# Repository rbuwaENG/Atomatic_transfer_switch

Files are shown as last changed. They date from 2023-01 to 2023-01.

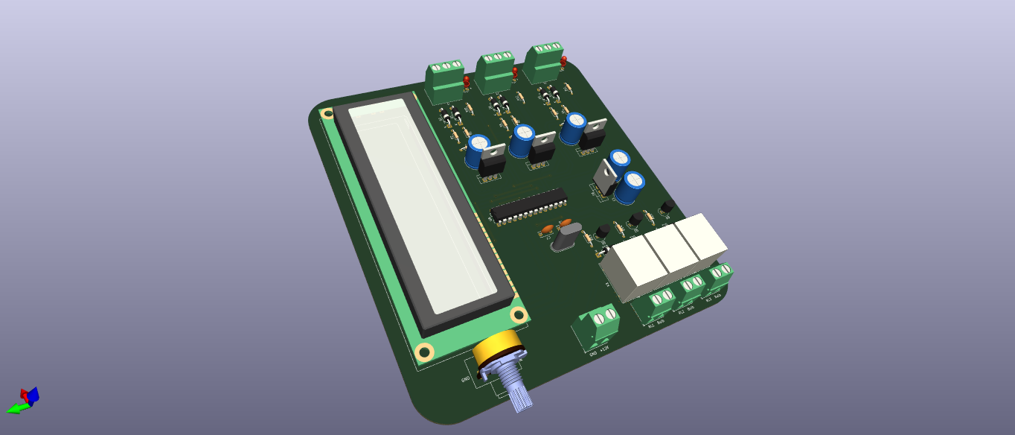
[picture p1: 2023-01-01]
pcb_design_kicad/src/img_2.png

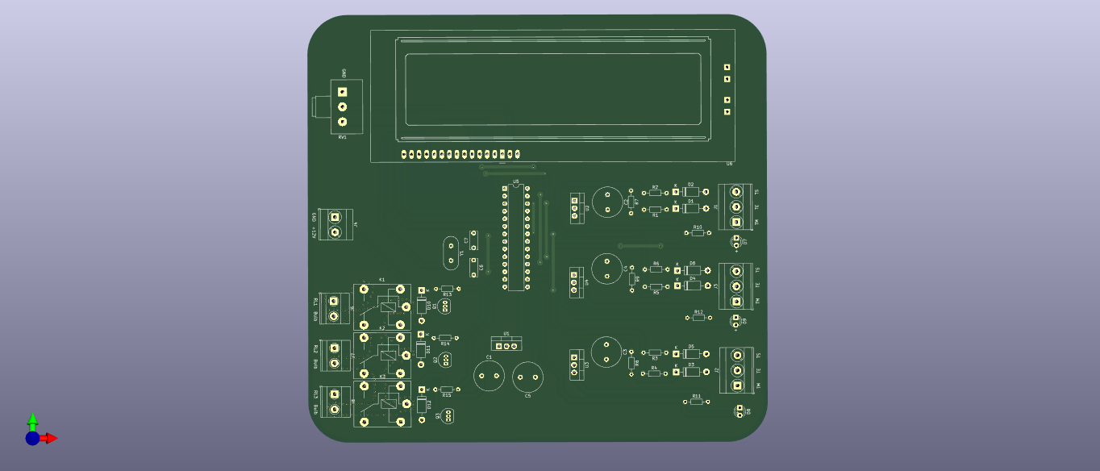
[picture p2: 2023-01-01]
pcb_design_kicad/src/img_3.png

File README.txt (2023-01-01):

░█████╗░████████╗░██████╗
██╔══██╗╚══██╔══╝██╔════╝
███████║░░░██║░░░╚█████╗░
██╔══██║░░░██║░░░░╚═══██╗
██║░░██║░░░██║░░░██████╔╝
╚═╝░░╚═╝░░░╚═╝░░░╚═════╝░
DESIGNED BY R.I BUWANEKA 
PCB,CIRCUIT DESIGNING SOLUTION 
WHATSAPP:0782532299

STEPS:
1.ARDUINO IDE-->IN PREFERENCE TICK UPLOAD 
2.THEN GET HEX FILE
1.UPLOAD HEX FILE FROM ARDUINO CODE
2.HIT PLAY BUTTON

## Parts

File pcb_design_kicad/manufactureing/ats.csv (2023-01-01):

Source: | /home/tharindu/Documents/Project/at_switch/ats/ats.kicad_sch
Date: | Sat 10 Sep 2022 11:17:41 AM +0530
Tool: | Eeschema 6.0.6-3a73a75311~116~ubuntu22.04.1
Generator: | /usr/share/kicad/plugins/bom_csv_grouped_by_value_with_fp.py
Component Count: | 53
Ref | Qnty | Value | Cmp name | Footprint | Description | Vendor
C1, C2, C3, C4, C5, | 5 | 2200u | C | Capacitor_THT:C_Radial_D10.0mm_H12.5mm_P5.00mm | Unpolarized capacitor
C6, C7, | 2 | 22p | C | Capacitor_THT:C_Disc_D6.0mm_W2.5mm_P5.00mm | Unpolarized capacitor
D1, D2, D3, D4, D5, D6, D10, D11, D12, | 9 | 1N4007 | 1N4007 | Diode_THT:D_DO-41_SOD81_P10.16mm_Horizontal | 1000V 1A General Purpose Rectifier Diode, DO-41
D7, D8, D9, | 3 | LED | LED | LED_THT:LED_D3.0mm | Light emitting diode
J1, J2, J3, | 3 | Screw_Terminal_01x03 | Screw_Terminal_01x03 | TerminalBlock_Phoenix:TerminalBlock_Phoenix_MKDS-3-3-5.08_1x03_P5.08mm_Horizontal | Generic screw terminal, single row, 01x03, script generated (kicad-library-utils/schlib/autogen/connector/)
J4, | 1 | Screw_Terminal_01x02 | Screw_Terminal_01x02 | TerminalBlock_Phoenix:TerminalBlock_Phoenix_MKDS-3-2-5.08_1x02_P5.08mm_Horizontal | Generic screw terminal, single row, 01x02, script generated (kicad-library-utils/schlib/autogen/connector/)
J5, | 1 | Screw_Terminal_01x04 | Screw_Terminal_01x04 | TerminalBlock_Phoenix:TerminalBlock_Phoenix_MKDS-3-4-5.08_1x04_P5.08mm_Horizontal | Generic screw terminal, single row, 01x04, script generated (kicad-library-utils/schlib/autogen/connector/)
K1, K2, K3, | 3 | FINDER-32.21-x300 | FINDER-32.21-x300 | Relay_THT:Relay_SPDT_Finder_36.11 | FINDER 32.21-x300, Single Pole Relay SPST-NO, 6A
Q1, Q2, Q3, | 3 | BC547 | BC547 | Package_TO_SOT_THT:TO-92_Inline | 0.1A Ic, 45V Vce, Small Signal NPN Transistor, TO-92
R1, R3, R5, | 3 | 100k | R | Resistor_THT:R_Axial_DIN0204_L3.6mm_D1.6mm_P7.62mm_Horizontal | Resistor
R2, R4, R6, R13, R14, R15, | 6 | 10k | R | Resistor_THT:R_Axial_DIN0204_L3.6mm_D1.6mm_P7.62mm_Horizontal | Resistor
R7, R8, R9, | 3 | 1k | R | Resistor_THT:R_Axial_DIN0204_L3.6mm_D1.6mm_P7.62mm_Horizontal | Resistor
R10, R11, | 2 | 330 | R | Resistor_THT:R_Axial_DIN0204_L3.6mm_D1.6mm_P7.62mm_Horizontal | Resistor
R12, | 1 | 300 | R | Resistor_THT:R_Axial_DIN0204_L3.6mm_D1.6mm_P7.62mm_Horizontal | Resistor
RV1, | 1 | 10k | R_Potentiometer | Potentiometer_THT:Potentiometer_Alps_RK163_Single_Horizontal | Potentiometer
U1, U2, U3, U4, | 4 | LM7805_TO220 | LM7805_TO220 | Package_TO_SOT_THT:TO-220-3_Vertical | Positive 1A 35V Linear Regulator, Fixed Output 5V, TO-220
U5, | 1 | ATmega328P-P | ATmega328P-P | Package_DIP:DIP-28_W7.62mm | 20MHz, 32kB Flash, 2kB SRAM, 1kB EEPROM, DIP-28
U6, | 1 | LCD-016N002L | LCD-016N002L | Display:LCD-016N002L | LCD 12x2, 8 bit parallel bus, 3V or 5V VDD
Y1, | 1 | Crystal | Crystal | Crystal:Crystal_HC18-U_Vertical | Two pin crystal

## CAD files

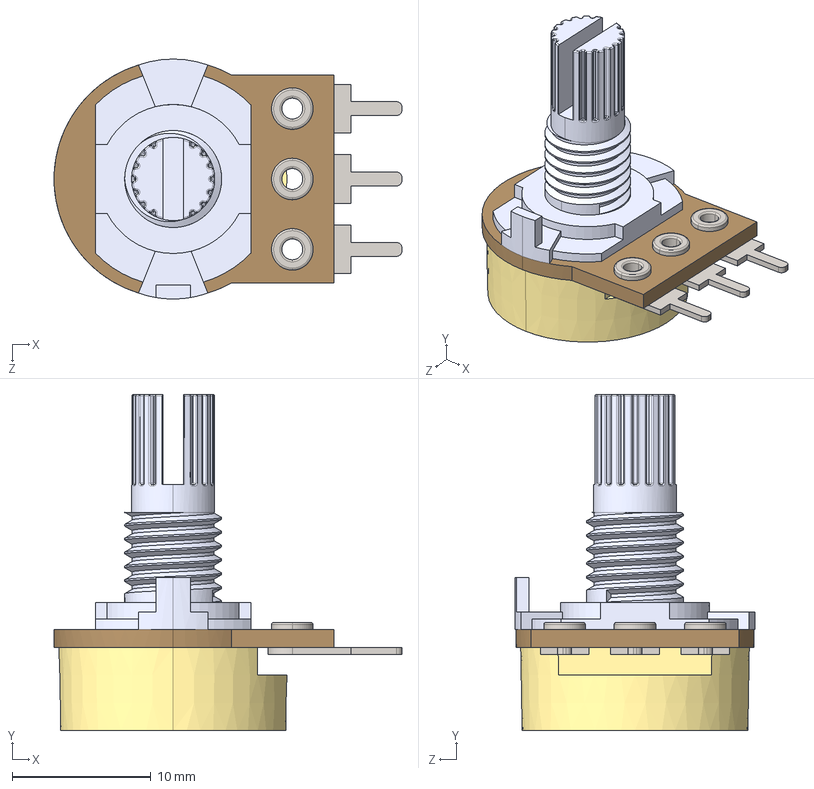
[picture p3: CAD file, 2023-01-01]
pcb_design_kicad/3d_model/potenciometer.STEP
25.1 x 24.2 x 17.3 mm

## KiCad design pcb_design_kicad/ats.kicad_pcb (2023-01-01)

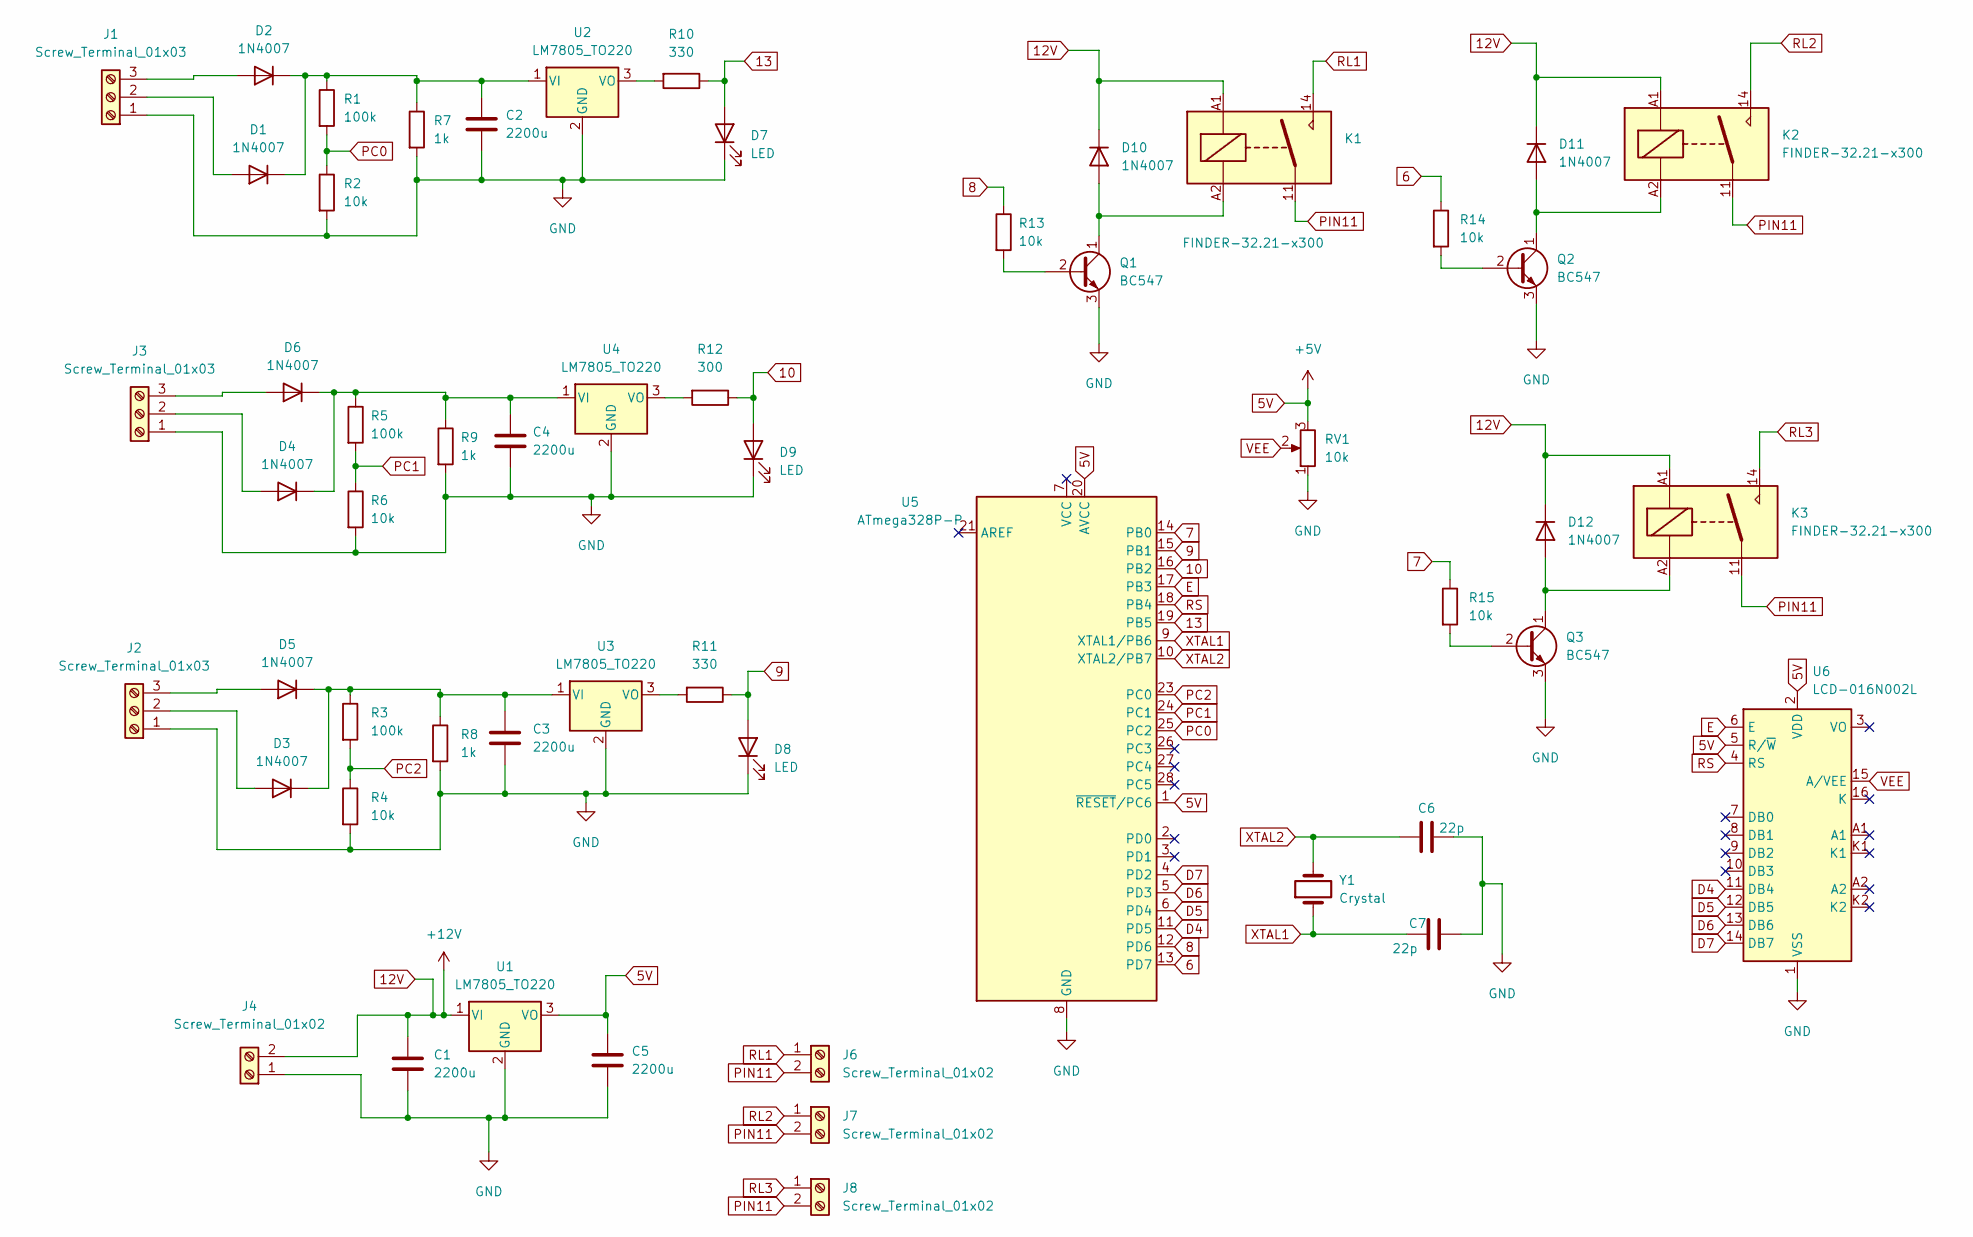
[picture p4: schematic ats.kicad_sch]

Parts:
C1, C2, C3, C4, C5: 2200u; C_Radial_D10.0mm_H12.5mm_P5.00mm
C6, C7: 22p; C_Disc_D6.0mm_W2.5mm_P5.00mm
D1, D2, D3, D4, D5, D6, D10, D11, D12: 1N4007; D_DO-41_SOD81_P10.16mm_Horizontal
D7, D8, D9: LED; LED_D3.0mm
J1, J2, J3: Screw_Terminal_01x03; TerminalBlock_Phoenix_MKDS-3-3-5.08_1x03_P5.08mm_Horizontal
J4: Screw_Terminal_01x02; TerminalBlock_Phoenix_MKDS-3-2-5.08_1x02_P5.08mm_Horizontal
J6, J7, J8: Screw_Terminal_01x02; TerminalBlock_Phoenix_MKDS-1,5-2-5.08_1x02_P5.08mm_Horizont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
K1, K2, K3: FINDER-32.21-x300; Relay_SPDT_Finder_36.11
Q1, Q2, Q3: BC547; TO-92_Inline
R1, R3, R5: 100k; R_Axial_DIN0204_L3.6mm_D1.6mm_P7.62mm_Horizontal
R2, R4, R6, R13, R14, R15: 10k; R_Axial_DIN0204_L3.6mm_D1.6mm_P7.62mm_Horizontal
R7, R8, R9: 1k; R_Axial_DIN0204_L3.6mm_D1.6mm_P7.62mm_Horizontal
R10, R11: 330; R_Axial_DIN0204_L3.6mm_D1.6mm_P7.62mm_Horizontal
R12: 300; R_Axial_DIN0204_L3.6mm_D1.6mm_P7.62mm_Horizontal
RV1: 10k; Potentiometer_Alps_RK163_Single_Horizontal
U1, U2, U3, U4: LM7805_TO220; TO-220-3_Vertical
U5: ATmega328P-P; DIP-28_W7.62mm
U6: LCD-016N002L
Y1: Crystal; Crystal_HC18-U_Vertical

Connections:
5V: C5.1, RV1.3, U1.3 (VO), U5.1 (~RESET/PC6), U5.20 (AVCC), U6.2 (VDD), U6.5 (R/~W)
6: R14.1, U5.13 (PD7)
7: R15.1, U5.14 (PB0)
8: R13.1, U5.12 (PD6)
9: D8.2 (A), R11.1, U5.15 (PB1)
10: D9.2 (A), R12.1, U5.16 (PB2)
12V: C1.1, D10.1 (K), D11.1 (K), D12.1 (K), J4.2, K1.A1, K2.A1, K3.A1, U1.1 (VI)
13: D7.2 (A), R10.1, U5.19 (PB5)
D4: U5.11 (PD5), U6.11 (DB4)
D5: U5.6 (PD4), U6.12 (DB5)
D6: U5.5 (PD3), U6.13 (DB6)
D7: U5.4 (PD2), U6.14 (DB7)
E: U5.17 (PB3), U6.6 (E)
GND: C1.2, C2.2, C3.2, C4.2, C5.2, C6.2, C7.2, D7.1 (K), D8.1 (K), D9.1 (K), J1.1, J2.1, J3.1, J4.1, Q1.3 (E), Q2.3 (E), Q3.3 (E), R2.2, R4.2, R6.2, R7.2, R8.2, R9.2, RV1.1, U1.2 (GND), U2.2 (GND), U3.2 (GND), U4.2 (GND), U5.8 (GND), U5.22 (GND), U6.1 (VSS)
unnamed: C2.1, D1.1 (K), D2.1 (K), R1.1, R7.1, U2.1 (VI)
unnamed: C3.1, D3.1 (K), D5.1 (K), R3.1, R8.1, U3.1 (VI)
unnamed: C4.1, D4.1 (K), D6.1 (K), R5.1, R9.1, U4.1 (VI)
unnamed: D1.2 (A), J1.2
unnamed: D2.2 (A), J1.3
unnamed: D3.2 (A), J2.2
unnamed: D4.2 (A), J3.2
unnamed: D5.2 (A), J2.3
unnamed: D6.2 (A), J3.3
unnamed: D10.2 (A), K1.A2, Q1.1 (C)
unnamed: D11.2 (A), K2.A2, Q2.1 (C)
unnamed: D12.2 (A), K3.A2, Q3.1 (C)
unnamed: Q1.2 (B), R13.2
unnamed: Q2.2 (B), R14.2
unnamed: Q3.2 (B), R15.2
unnamed: R10.2, U2.3 (VO)
unnamed: R11.2, U3.3 (VO)
unnamed: R12.2, U4.3 (VO)
PC0: R1.2, R2.1, U5.25 (PC2)
PC1: R5.2, R6.1, U5.24 (PC1)
PC2: R3.2, R4.1, U5.23 (PC0)
PIN11: J6.2, J7.2, J8.2, K1.11, K2.11, K3.11
RL1: J6.1, K1.14
RL2: J7.1, K2.14
RL3: J8.1, K3.14
RS: U5.18 (PB4), U6.4 (RS)
VEE: RV1.2, U6.15 (A/VEE)
XTAL1: C7.1, U5.9 (XTAL1/PB6), Y1.1
XTAL2: C6.1, U5.10 (XTAL2/PB7), Y1.2

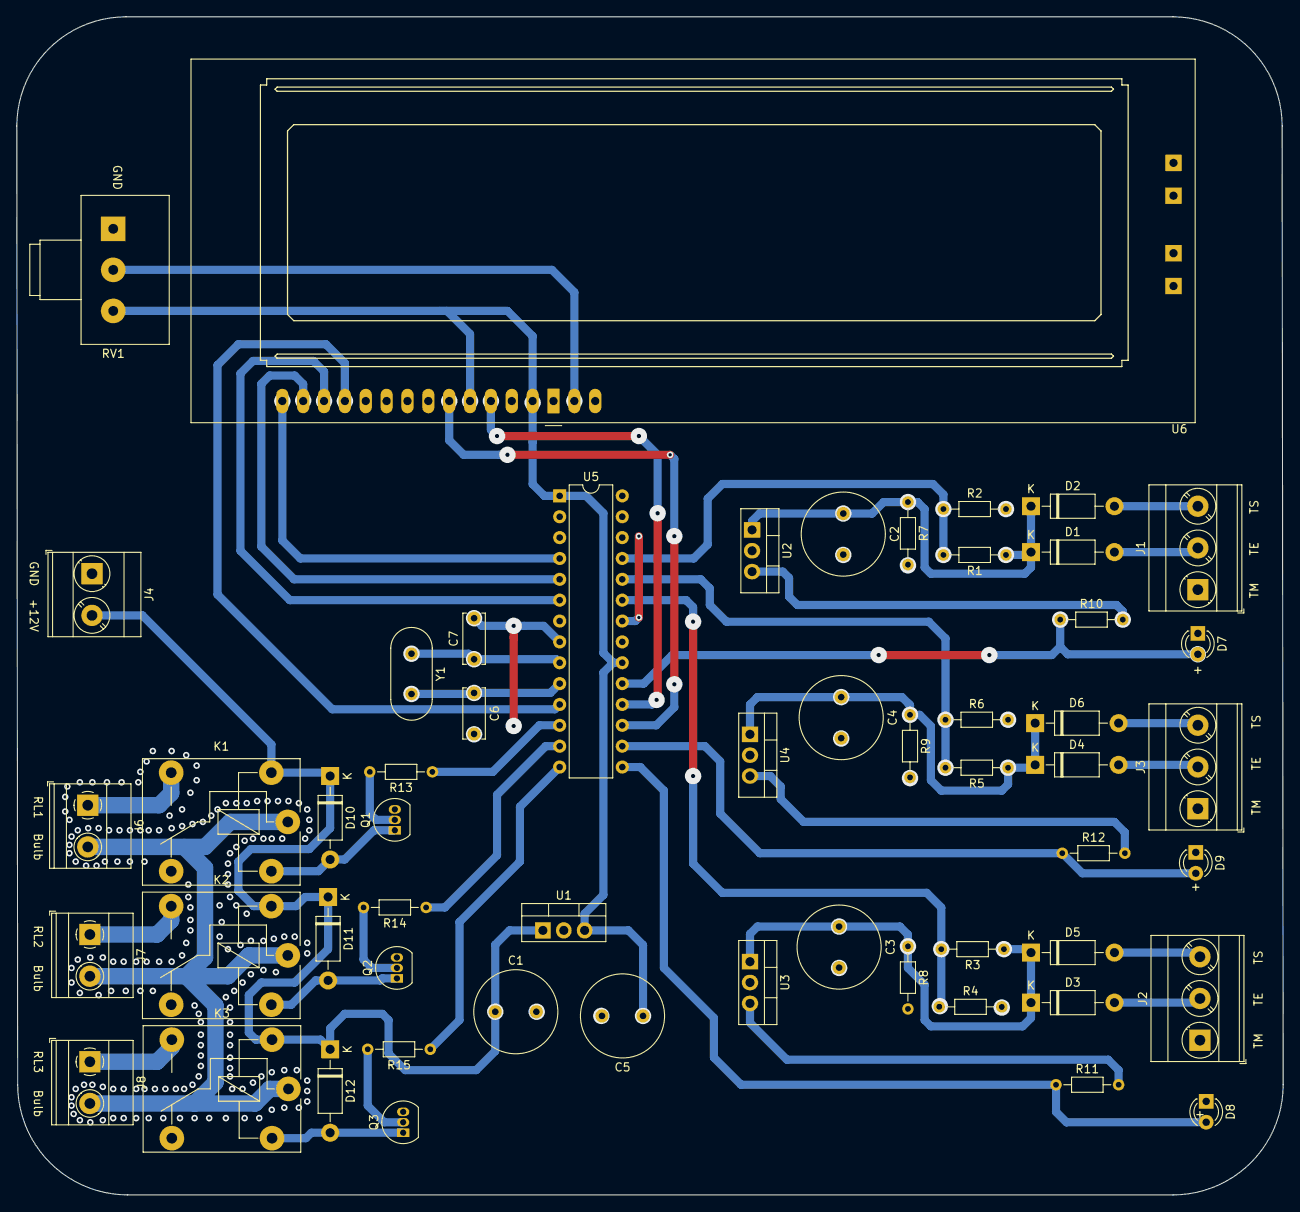
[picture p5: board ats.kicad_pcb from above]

Board: 2 copper layers, 154.2 x 143.5 mm, 55 parts (0 on the bottom side), 43 nets.

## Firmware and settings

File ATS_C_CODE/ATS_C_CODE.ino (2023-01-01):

/*
╔═══╦════╦═══╗
║╔═╗║╔╗╔╗║╔═╗║
║║─║╠╝║║╚╣╚══╗
║╚═╝║─║║─╚══╗║
║╔═╗║─║║─║╚═╝║
╚╝─╚╝─╚╝─╚═══╝

DATE 
2022/8/30
*/
#include <LiquidCrystal.h>
const int rs = 12, en = 11, d4 = 5, d5 = 4, d6 = 3, d7 = 2;
LiquidCrystal lcd(rs, en, d4, d5, d6, d7);

//delay
int d1 = 1000;
float CalVal = 11.08433; 

//Timing variables
unsigned long previousMillis = 0;
const long interval = 200;          //Interval to read voltages

// input pins 
const int redPhaseIn = 13;
const int yellowPhaseIn = 10;
const int bluePhaseIn = 9;

// output pins 
const int redPhaseOut = 6;
const int yellowPhaseOut = 7;
const int bluePhaseOut = 8;

// variable for reading input phase status. initial false
bool redState = false;
bool yellowState = false;
bool blueState = false;
bool allPhaseOn = false;

//variable states initial low
int redPhaseState = LOW;
int yellowPhaseState = LOW;
int bluePhaseState = LOW;


void setup() {
  
//set pins  
pinMode(redPhaseIn, INPUT);
pinMode(yellowPhaseIn, INPUT);
pinMode(bluePhaseIn, INPUT);

pinMode(redPhaseOut, OUTPUT);
pinMode(yellowPhaseOut, OUTPUT);
pinMode(bluePhaseOut, OUTPUT);

pinMode(A0,INPUT);
pinMode(A1,INPUT);
pinMode(A2,INPUT);

//Initialize serial monitor
Serial.begin(9600);
Serial.println("3 PHASE AUTOMATIC CHANGE OVER SYSTEM");
delay (2000);
Serial.println("Processing available PHASE lines...");
  // initialize the LCD
  analogWrite(8,25);
  lcd.begin(16, 2);  
  lcd.print("3PHASE POWER SYS!");
  delay(2000);
  lcd.setCursor(0,1);
  lcd.print("Initializing sys"); 
  digitalWrite ( redPhaseOut,LOW);
  digitalWrite ( yellowPhaseOut,LOW);
  digitalWrite ( bluePhaseOut,LOW);
  delay(2000);
}

void loop() {
  //millis for multi taskig
   unsigned long currentMillis = millis();
  //check state of each input
     redPhaseState = digitalRead(redPhaseIn);
     yellowPhaseState = digitalRead(yellowPhaseIn);
     bluePhaseState = digitalRead(bluePhaseIn);
/*
╔═══╦╗╔╗─╔═══╦╗
║╔═╗║║║║─║╔═╗║║
║║─║║║║║─║╚═╝║╚═╦══╦══╦══╗
║╚═╝║║║║─║╔══╣╔╗║╔╗║══╣║═╣
║╔═╗║╚╣╚╗║║──║║║║╔╗╠══║║═╣
╚╝─╚╩═╩═╝╚╝──╚╝╚╩╝╚╩══╩══╝
*/   
  if ( redPhaseState == HIGH && yellowPhaseState == HIGH && bluePhaseState == HIGH && currentMillis - previousMillis >= interval && allPhaseOn == false )
  {
    allPhaseOn = checkallPhase();
    previousMillis = currentMillis;
    Serial.println("All Phase are On");
    lcd.clear();
    lcd.setCursor (0,0); // set to line 1, char 0  
    lcd.print("3PHASE POWER SYS");

    delay (d1);
    lcd.setCursor (0,1); // set to line 1, char 0  
    lcd.print("All phase are ON!");
    digitalWrite ( redPhaseOut,HIGH);
    digitalWrite ( yellowPhaseOut,LOW);
    digitalWrite ( bluePhaseOut,LOW);
    delay (d1);
    lcd.clear();
    while(allPhaseOn == true){
        
        lcd.setCursor (0,0); // set to line 1, char 0  
        lcd.print("CEB IN USE");
        lcd.setCursor (0,1); // set to line 1, char 0  
        lcd.print(voltageReading(A2));
        lcd.setCursor(6,1);
        lcd.print("V input");
        allPhaseOn = checkallPhase();
    }   
   }
   else{
/*
╔═══╗────╔╗╔═══╦╗
║╔═╗║────║║║╔═╗║║
║╚═╝╠══╦═╝║║╚═╝║╚═╦══╦══╦══╗
║╔╗╔╣║═╣╔╗║║╔══╣╔╗║╔╗║══╣║═╣
║║║╚╣║═╣╚╝║║║──║║║║╔╗╠══║║═╣
╚╝╚═╩══╩══╝╚╝──╚╝╚╩╝╚╩══╩══╝
*/
 
    if ( redPhaseState == HIGH)
      {
      Serial.println("CEB is on");
      
    lcd.clear();
    lcd.setCursor (0,0); // set to line 1, char 0  
    lcd.print("3PHASE POWER SYS");
    
    delay (d1);
   
    digitalWrite ( redPhaseOut,HIGH);
    digitalWrite ( yellowPhaseOut,LOW);
    digitalWrite ( bluePhaseOut,LOW);
    delay (d1);
    lcd.clear();
    
    while( checkRedPhase()== true && checkallPhase() == false ){
      
      lcd.setCursor (0,0); // set to line 1, char 0  
      lcd.print("CEB IN USE");
      lcd.setCursor (0,1); // set to line 1, char 0  
      lcd.print(voltageReading(A2));
      lcd.setCursor(6,1);
      lcd.print("V input");
      redState = checkRedPhase();
    }
      }
/*
╔╗──╔╗─╔╗╔╗─────────╔═══╦╗
║╚╗╔╝║─║║║║─────────║╔═╗║║
╚╗╚╝╔╩═╣║║║╔══╦╗╔╗╔╗║╚═╝║╚═╦══╦══╦══╗
─╚╗╔╣║═╣║║║║╔╗║╚╝╚╝║║╔══╣╔╗║╔╗║══╣║═╣
──║║║║═╣╚╣╚╣╚╝╠╗╔╗╔╝║║──║║║║╔╗╠══║║═╣
──╚╝╚══╩═╩═╩══╝╚╝╚╝─╚╝──╚╝╚╩╝╚╩══╩══╝
*/
      else if ( yellowPhaseState == HIGH  )
      {
      
       Serial.println("Solar is on"); 
        lcd.clear();
    lcd.setCursor (0,0); // set to line 1, char 0  
    lcd.print("3PHASE POWER SYS");
    
    delay (d1);
    lcd.setCursor (0,1); // set to line 1, char 0  
    lcd.print("Solar ON!");
    digitalWrite ( redPhaseOut,LOW);
    digitalWrite ( yellowPhaseOut,HIGH);
    digitalWrite ( bluePhaseOut,LOW);
    delay (d1);
    lcd.clear();
    
    while(checkYellowPhase() == true && checkRedPhase()==false ){
      lcd.setCursor (0,0); // set to line 1, char 0  
      lcd.print("Solar ON!");
      lcd.setCursor (0,1); // set to line 1, char 0  
      lcd.print(voltageReading(A1));
      lcd.setCursor(6,1);
      lcd.print("V input");
      yellowState = checkYellowPhase();
    }
    
      }
/*
╔══╗╔╗───────╔═══╦╗
║╔╗║║║───────║╔═╗║║
║╚╝╚╣║╔╗╔╦══╗║╚═╝║╚═╦══╦══╦══╗
║╔═╗║║║║║║║═╣║╔══╣╔╗║╔╗║══╣║═╣
║╚═╝║╚╣╚╝║║═╣║║──║║║║╔╗╠══║║═╣
╚═══╩═╩══╩══╝╚╝──╚╝╚╩╝╚╩══╩══╝
*/ 
      else if ( bluePhaseState == HIGH)
      {
       Serial.println("Generator is on"); 
        lcd.clear();
    lcd.setCursor (0,0); // set to line 1, char 0  
    lcd.print("3PHASE POWER SYS");
   
    delay (d1);
    lcd.setCursor (0,1); // set to line 1, char 0  
    lcd.print("Generator ON!");
    digitalWrite ( redPhaseOut,LOW);
    digitalWrite ( yellowPhaseOut,LOW);
    digitalWrite ( bluePhaseOut,HIGH);   
    delay (d1);
    lcd.clear();
    
    while(checkBluePhase()== true &&  checkRedPhase()==false && checkYellowPhase()== false ){
      lcd.setCursor (0,0); // set to line 1, char 0  
      lcd.print("Generator IS ON!");
      lcd.setCursor (0,1); // set to line 1, char 0  
      lcd.print(voltageReading(A0));
      lcd.setCursor(6,1);
      lcd.print("V input");
      blueState = checkBluePhase();
    }
      }
/*
╔═══╦╗──╔╗───╔═══╦╗─╔╦═══╦═══╦═══╗╔═══╦═══╦═══╗
║╔═╗║║──║║───║╔═╗║║─║║╔═╗║╔═╗║╔══╝║╔═╗║╔══╣╔══╝
║║─║║║──║║───║╚═╝║╚═╝║║─║║╚══╣╚══╗║║─║║╚══╣╚══╗
║╚═╝║║─╔╣║─╔╗║╔══╣╔═╗║╚═╝╠══╗║╔══╝║║─║║╔══╣╔══╝
║╔═╗║╚═╝║╚═╝║║║──║║─║║╔═╗║╚═╝║╚══╗║╚═╝║║──║║
╚╝─╚╩═══╩═══╝╚╝──╚╝─╚╩╝─╚╩═══╩═══╝╚═══╩╝──╚╝
*/ 
      else
      {
        Serial.println("All phases are off");
         lcd.clear();
    lcd.setCursor (0,0); // set to line 1, char 0  
    lcd.print("3PHASE POWER SYS");
    
    delay (d1);
    
    digitalWrite ( redPhaseOut,LOW);
    digitalWrite ( yellowPhaseOut,LOW);
    digitalWrite ( bluePhaseOut,LOW);

    while(checkRedPhase()==false && checkYellowPhase()==false && checkBluePhase()==false){
    lcd.setCursor (0,1); // set to line 1, char 0  
    lcd.print("ALL PHASE OFF!");
    }
    
    
      }
      }
      
}
/*
╔═══╦╗─╔╦═╗─╔╦═══╦════╦══╦═══╦═╗─╔╦═══╗
║╔══╣║─║║║╚╗║║╔═╗║╔╗╔╗╠╣╠╣╔═╗║║╚╗║║╔═╗║
║╚══╣║─║║╔╗╚╝║║─╚╩╝║║╚╝║║║║─║║╔╗╚╝║╚══╗
║╔══╣║─║║║╚╗║║║─╔╗─║║──║║║║─║║║╚╗║╠══╗║
║║──║╚═╝║║─║║║╚═╝║─║║─╔╣╠╣╚═╝║║─║║║╚═╝║
╚╝──╚═══╩╝─╚═╩═══╝─╚╝─╚══╩═══╩╝─╚═╩═══╝
*/

//check all state
bool checkallPhase(){
  bool nstate;
  if( checkRedPhase() == true && checkYellowPhase() == true && checkBluePhase() == true){nstate = true;}
  else{nstate = false;}
  delay(50);  
  return nstate;//return bool value
  
}

//check red state 
bool checkRedPhase(){
  bool nstate;
  redPhaseState = digitalRead(redPhaseIn);
  if(redPhaseState == HIGH){nstate = true;}
  else{nstate = false;}
  delay(50);  
  return nstate;//return bool value
  
  }

//check yellow state 
bool checkYellowPhase(){
  bool nstate;
  yellowPhaseState = digitalRead(yellowPhaseIn);
  if( yellowPhaseState == HIGH){nstate = true;}
  else{nstate = false;}
  delay(50);
  return nstate;//return bool value
    
  }

//check blue state 
bool checkBluePhase(){
  bool nstate;
   bluePhaseState = digitalRead(bluePhaseIn);
  if( bluePhaseState == HIGH){nstate = true;}
  else{nstate = false;}
  delay(50);  
  return nstate;//return bool value
  
  }

//voltage reding function
float voltageReading(int analogPin){
    float VIn = (analogRead(analogPin)* 5) / 1024.00;     //Convert 10bit input to an actual voltage
    float Voltage = (VIn * CalVal)+0.90;
    float AC_LOW_VOLT = Voltage;
    float AC_HIGH_VOLT = ( AC_LOW_VOLT * 12.3284);
    delay(50);
    return AC_HIGH_VOLT;
    
}

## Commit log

2023-01-01 final project
    [ats-B_Cu.gbr, ats-B_Mask.gbr, ats-B_Paste.gbr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]
2023-01-01 update pcb
    [ats-B_Cu.gbr, ats-B_Mask.gbr, ats-B_Paste.gbr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]
